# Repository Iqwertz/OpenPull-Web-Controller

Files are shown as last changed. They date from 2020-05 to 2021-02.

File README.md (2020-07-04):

# OpenPull-Web-Controller
---

## Introduction
The OpenPull-Web-Controller is an upgrade for the [DIY Universal test machine](https://github.com/CNCKitchen/Open-Pull) by [CNCKitchen](https://github.com/CNCKitchen).
It ads Bluetooth and Sd functionality to the test Maschine. 
The machine can be controlled over this webinterface: [https://iqwertz.github.io/OpenPullController/](https://iqwertz.github.io/OpenPullController/)

# Upgrade it
---

## Additional Hardware/ and Cad files
---

### CAD
There is an additional cad files for the Sdcard and Ble module holder available.

### Additional Hardware
- DC to Dc Buck Converter 24V-5V
- HM10 Ble Module
- Arduino MicroSD Card Module
- MicroSD Card

### Electronics
Currently the electronics are only as schematics and as images.
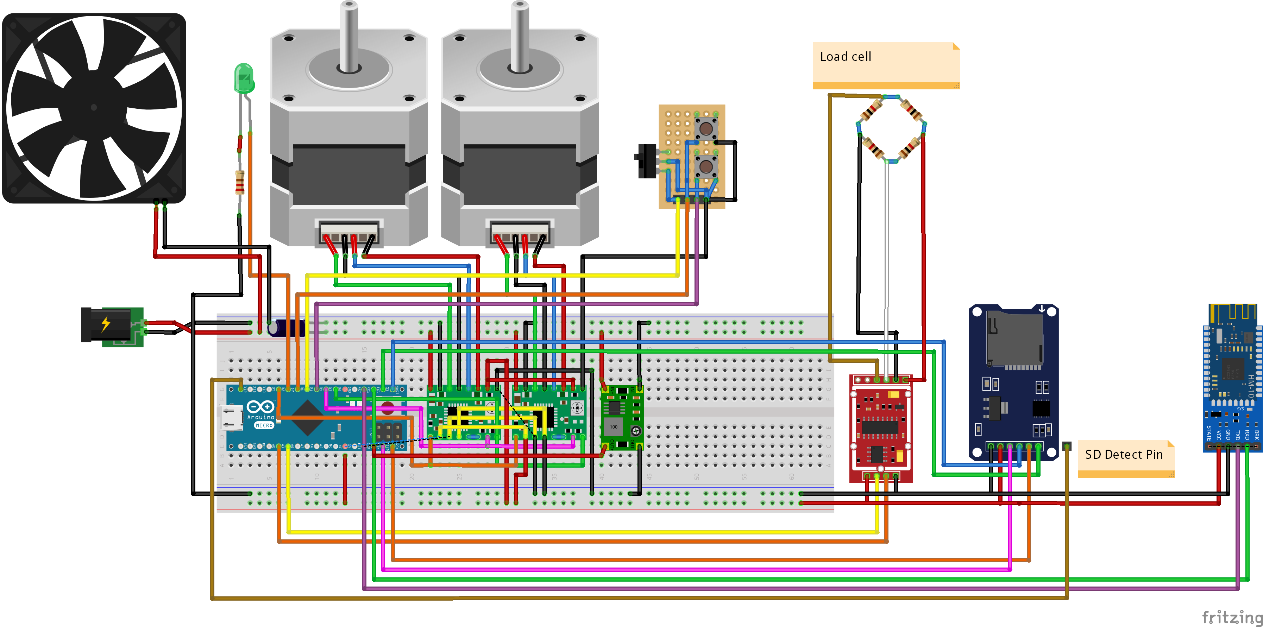
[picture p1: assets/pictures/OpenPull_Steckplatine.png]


Note:

My scematics are for an arduino micro since it was the only one laying around and it has integrated SPI and Serial pins. The code can be modified to use the arduino nano with the software serial library. If there is an interest for it add it as an issue.

Adding an Sd Detect Pin:

My SD card Module didn't had an Sd Detect pin but I found out that it can be added very easy. Just solder a wire to the left pin on the module (red circle in the Picture) and wire it according to the scematics.

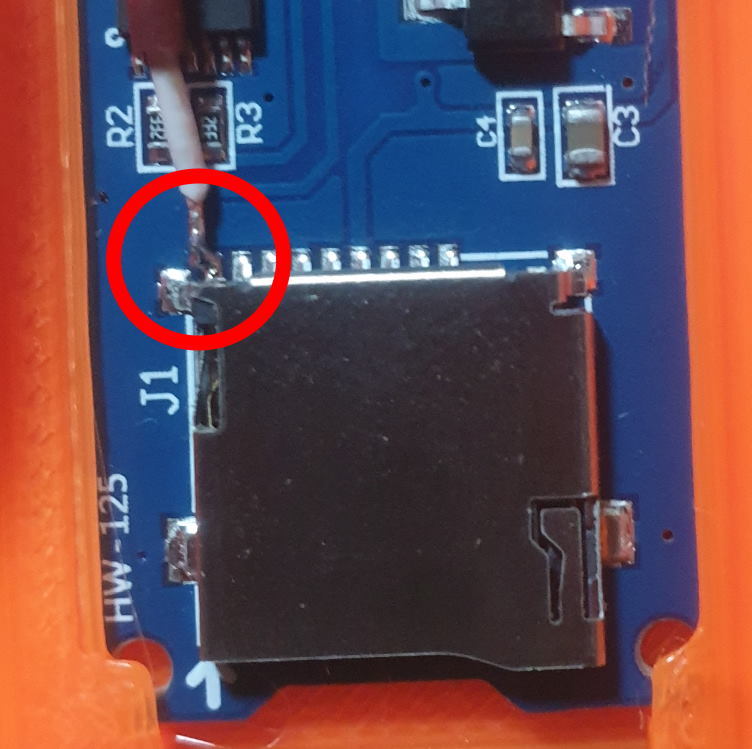
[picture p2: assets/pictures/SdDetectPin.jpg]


## Set Up
---

When everything is wired up, upload the OpenPull.ino to the arduino. Then insert an empty SDcard and plugin the power supply. The Maschine is now ready.

When the Maschine isnt moving the correct amount of distance you need to adjust the stepsPerMM var in the code.
```C++

long stepsPerMM = 39000;

```

## Use 
---

To use the Maschine go to [https://iqwertz.github.io/OpenPullController/](https://iqwertz.github.io/OpenPullController/).

Click on the Bluetooth Symbol in the Top left corner and select the Maschine (The Name is most of the time the producers Name. Mine is DSD Tech as an example.) When the connection is succesfull, you should be able to move it up and down by clicking the arrows.

### Interface
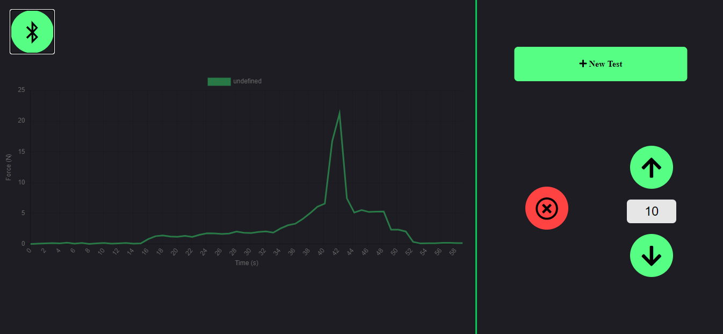
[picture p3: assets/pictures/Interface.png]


Notes:

With the red Button any Movement can be stopped

The number Field between the up/down arrows is the Move distance in mm when an arrow is clicked.
### Starting a new Test

To Start a new Test press the "New Test" Button

In the "New Test" Window, the Metadata of the Test can be set. It will be saved in the Test file. When the "Start Test" Button on the bottom of the page is pressed the Metadata will be sent the maschine and the test will be started.

Note:
When the progress indicator isnt increasing for some time reset the arduino and the page and retry.

### Data Processing
When an SD Card is inserted, test Data will get saved to it. It is located in an "OPENPULL" folder. 

!!!Important: Do not delete the index.txt file. It keeps track of the last file index. If you want to delete the whole Test Data delete the Folder!!!

To view the Test Data the [online Viewer](https://iqwertz.github.io/Visualizer/) can be used! 

Repository of the Data Visualizer: [github.com/Iqwertz/OpenPullTestDataVisualizer](https://github.com/Iqwertz/OpenPullTestDataVisualizer)

Example of a test File (JSON):

```JSON
{
  "MetaData": {
    "Name": "Infill 40%",
    "Date": "2020/05/28 19:32:53",
    "Parameter": {
      "Orientation": "Lying ",
      "Material": "PLA ",
      "Infill Type": "Gyroid ",
      "Orientation": "Lying ",
      "Material": "PLA ",
      "Infill Type": "Gyroid ",
      "Orientation": "Lying ",
      "Material": "PLA ",
      "Infill Type": "Gyroid ",
      "Infill": "15 %",
      "Layer Height": "0.3 mm",
      "First Layer Height": "0.3 mm",
      "Nozzle Size": "0.5 mm",
      "Bed Temperatur": "70 °",
      "Nozzle Temperatur": "200 °",
      "Vertical Shells": "3 ",
      "Top Layers": "3 ",
      "Bottom Layers": "3 "
    },
    "TestMode": "M14 A1",
    "Notes": ""
  },
  "Data": [
    0,
    1,
    3,
    6,
    10,
    0
  ],
  "MeasuringIntervall": 0.15,
  "BreakPoint": 419.00,
  "Maximum": 454.65
}
```

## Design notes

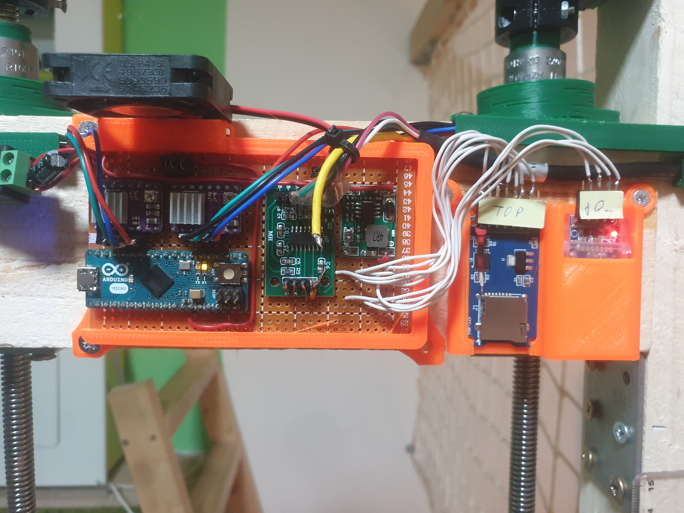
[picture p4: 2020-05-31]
assets/pictures/ElectronicsPhoto.jpg

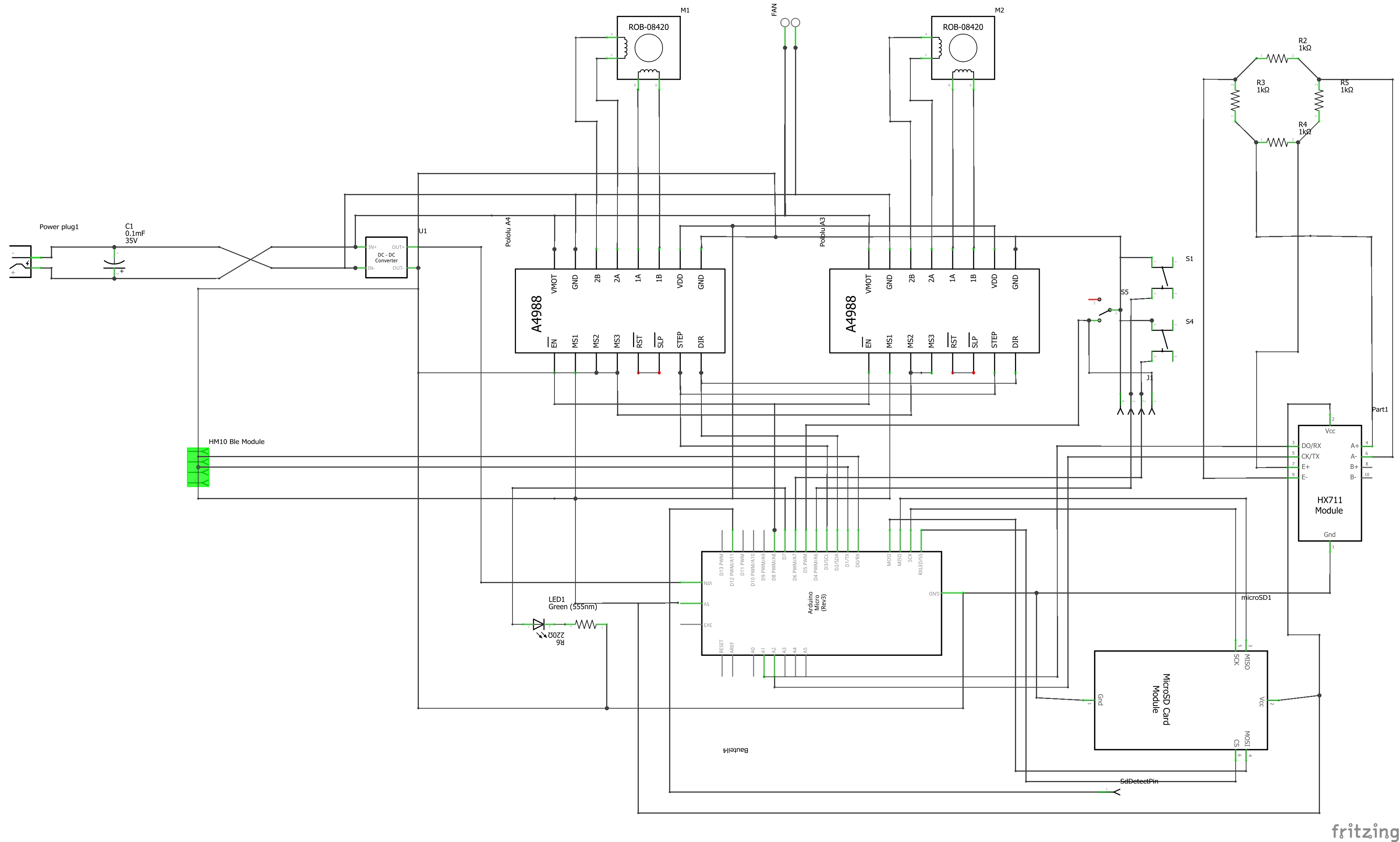
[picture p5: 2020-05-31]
OpenPull/Electronics/OpenPull_Schaltplan.png

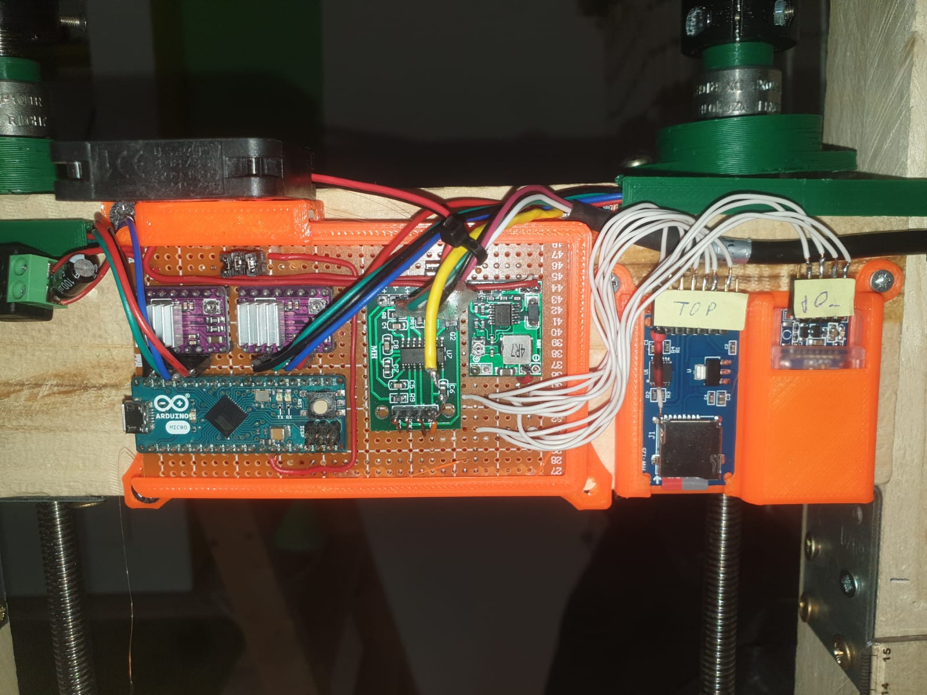
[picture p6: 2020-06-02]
OpenPull/CAD/UseofCases.jpeg

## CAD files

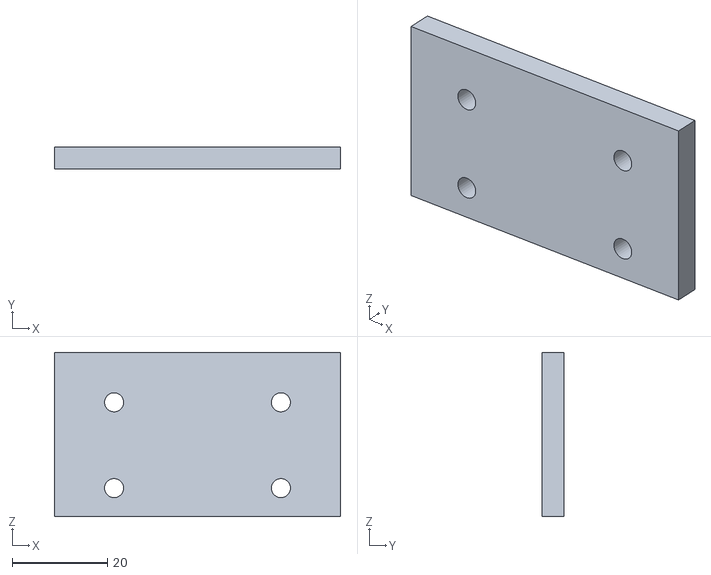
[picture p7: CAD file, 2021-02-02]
OpenPull/CAD/DriverTopSpacer.stl
60.0 x 4.70 x 34.5

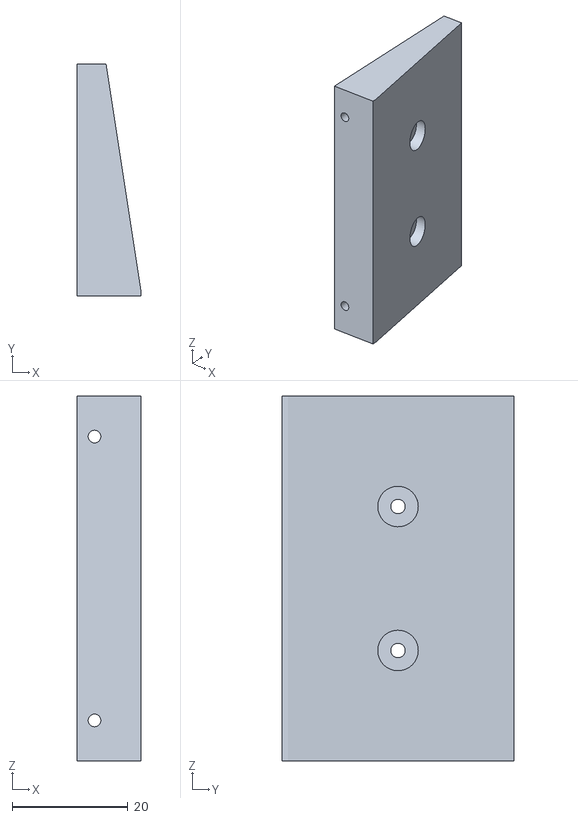
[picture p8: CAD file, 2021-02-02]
OpenPull/CAD/Schräge1.stl
11.0 x 40.0 x 63.0

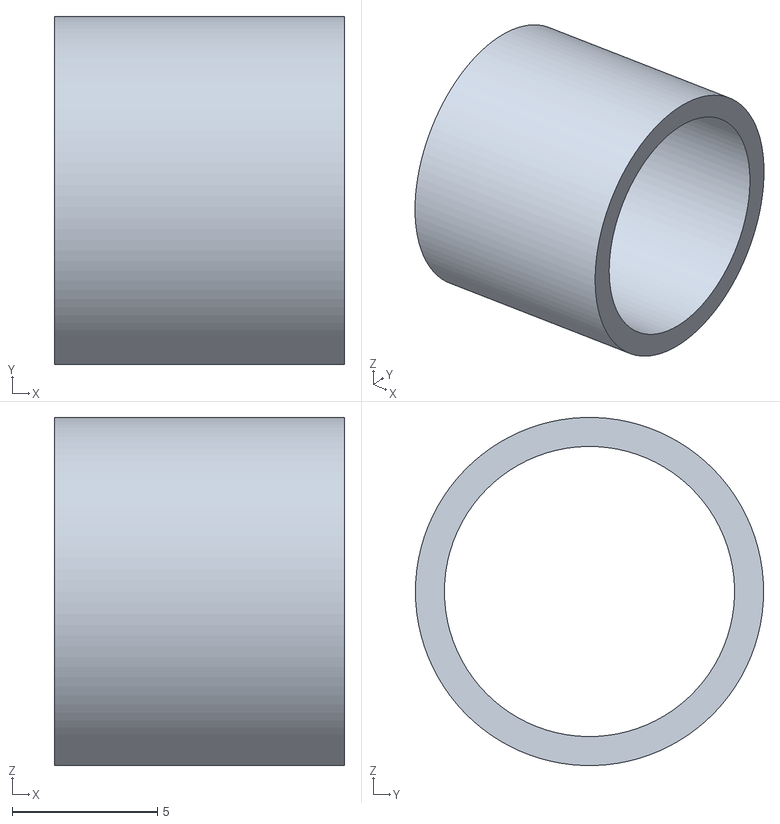
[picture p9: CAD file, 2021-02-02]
OpenPull/CAD/SPacer RS6201.stl
10.0 x 12.0 x 12.0

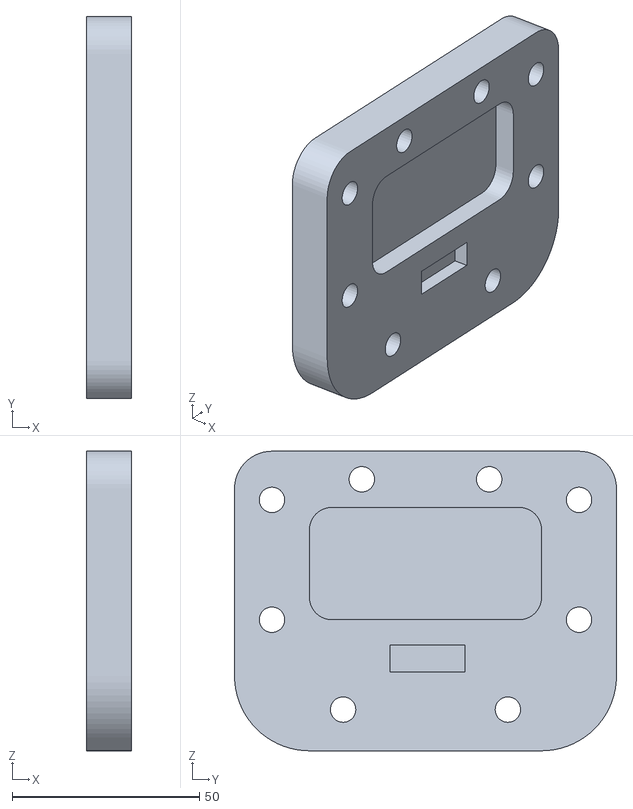
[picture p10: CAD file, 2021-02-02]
OpenPull/CAD/Clampback.stl
12.0 x 102.0 x 80.0

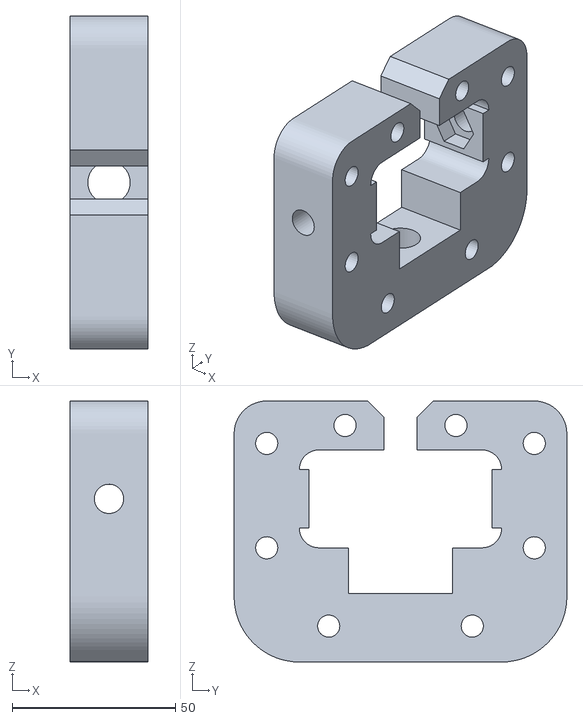
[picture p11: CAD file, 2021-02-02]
OpenPull/CAD/Clampcenterbot.stl
24.0 x 102.0 x 80.0

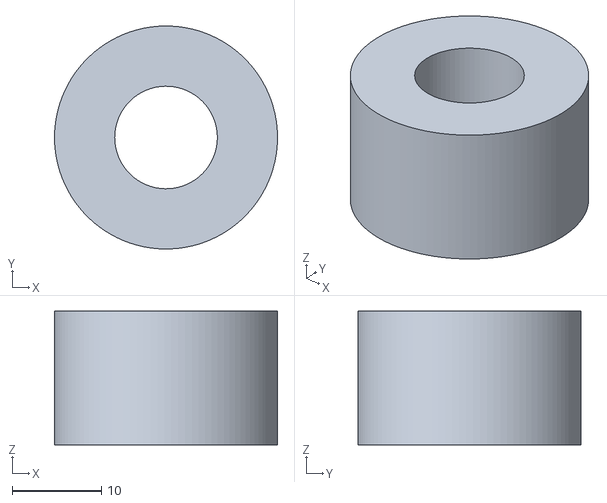
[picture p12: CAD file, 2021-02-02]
OpenPull/CAD/ClampSpaceHolder.stl
25.0 x 25.0 x 15.0

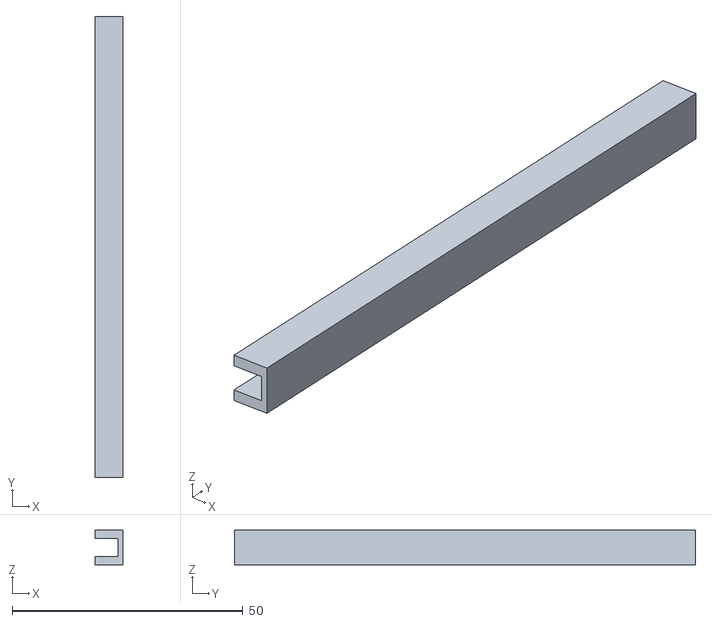
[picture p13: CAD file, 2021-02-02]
OpenPull/CAD/Leitung3.stl
6.00 x 100.0 x 7.50

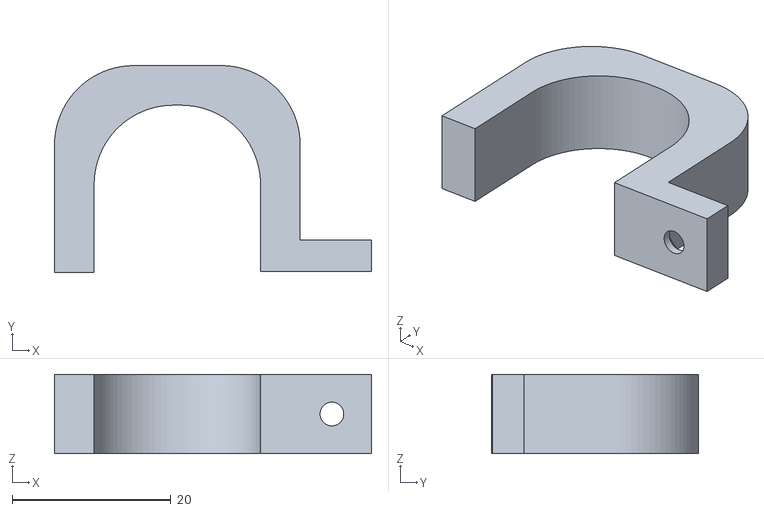
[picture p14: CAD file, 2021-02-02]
OpenPull/CAD/PSU Kabel Klemme.stl
40.0 x 26.1 x 10.0

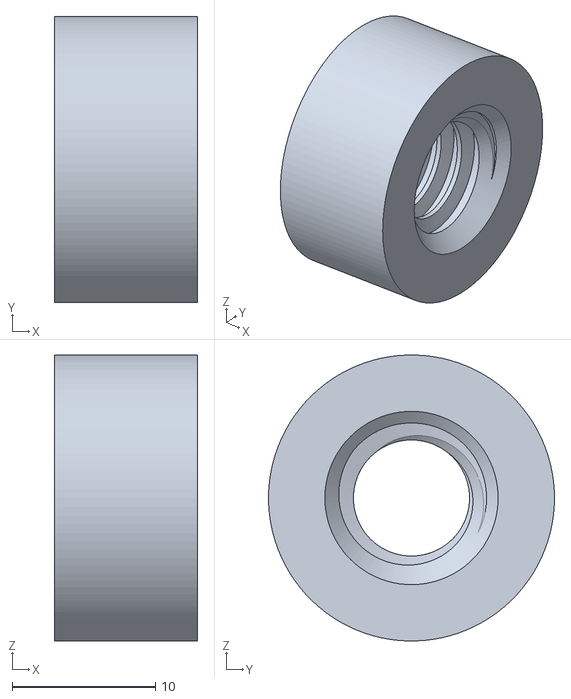
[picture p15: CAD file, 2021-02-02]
OpenPull/CAD/Counternut.stl
10.0 x 20.0 x 20.0

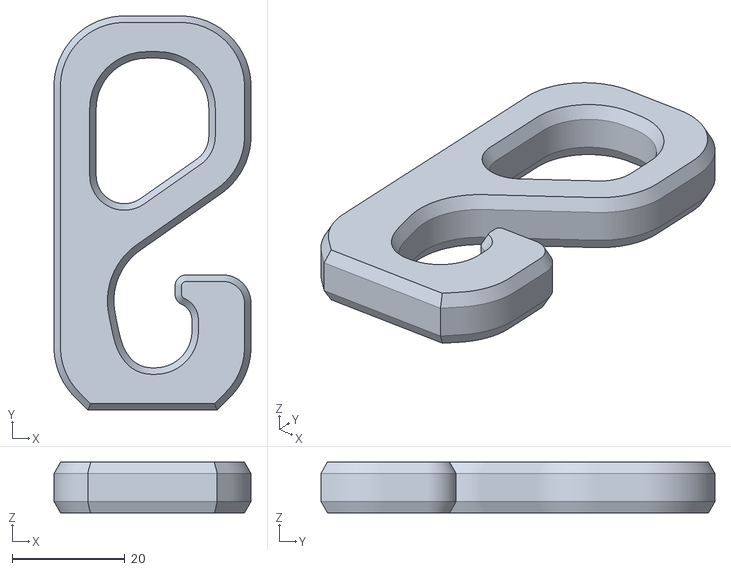
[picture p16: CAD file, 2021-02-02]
OpenPull/CAD/testHook_noSlots (1).stl
35.0 x 70.0 x 9.00

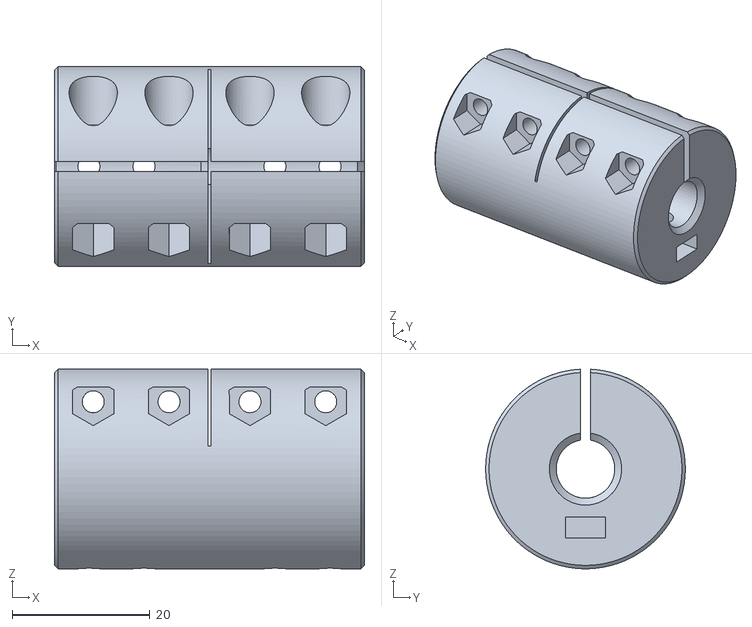
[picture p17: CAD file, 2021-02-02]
OpenPull/CAD/Coupling.stl
45.0 x 29.0 x 29.0

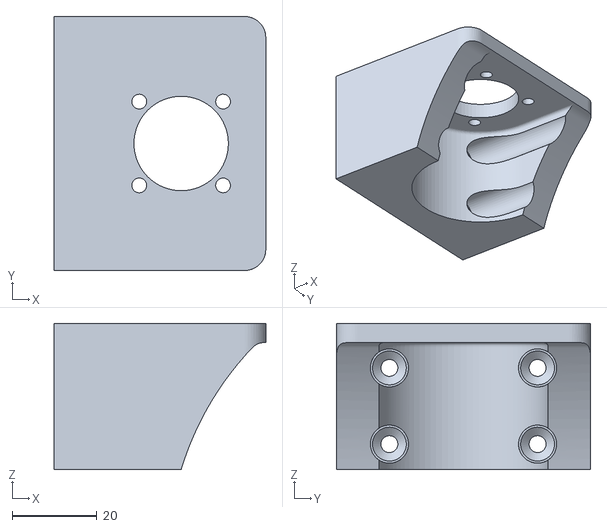
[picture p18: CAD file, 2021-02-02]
OpenPull/CAD/Driver.stl
50.0 x 60.0 x 34.5

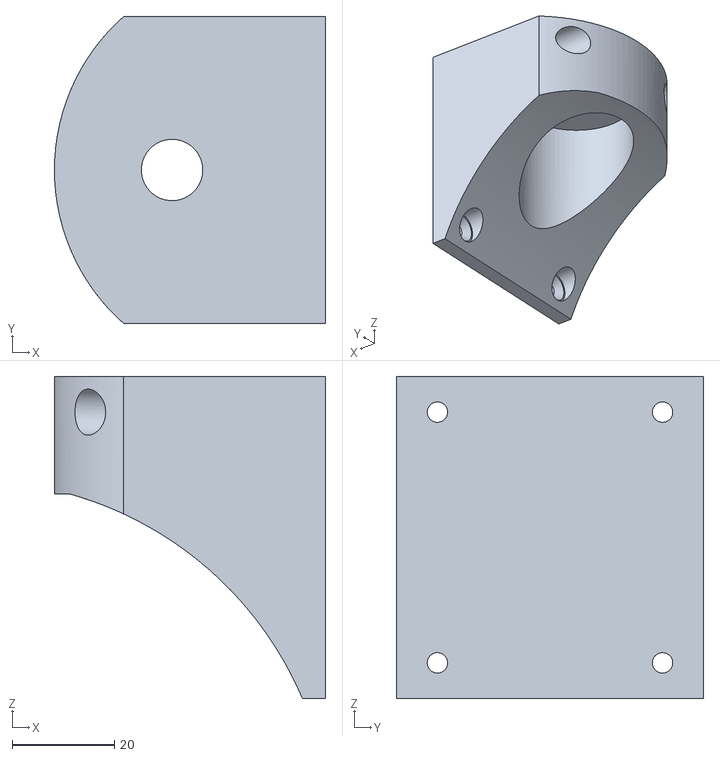
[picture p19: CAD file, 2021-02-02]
OpenPull/CAD/DriverBottom.stl
53.0 x 60.0 x 63.0

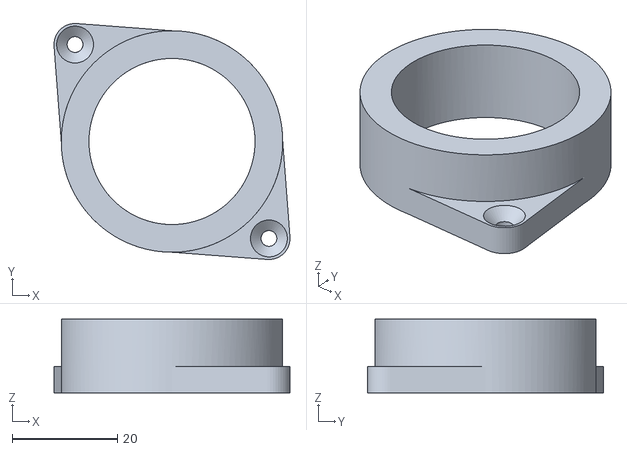
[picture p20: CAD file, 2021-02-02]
OpenPull/CAD/axialnutholder.stl
44.8 x 44.8 x 14.0

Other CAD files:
OpenPull/CAD/Spacer.stl
OpenPull/CAD/PSU CASE.stl
OpenPull/CAD/UHakenSpacer.stl
OpenPull/CAD/BleSdCase.stl
OpenPull/CAD/BleSdCardMount.stl
OpenPull/CAD/BoardMount.stl
OpenPull/CAD/Clampbreak.stl
OpenPull/CAD/Clampfront.stl
OpenPull/CAD/Dreher.stl
OpenPull/CAD/DriverBottomSpacer.stl
OpenPull/CAD/Electroniccase.stl
OpenPull/CAD/Leitung1.stl
OpenPull/CAD/Leitung2.stl
OpenPull/CAD/Loadcell Kabel Eck.stl
OpenPull/CAD/Loadcell Kabel Klemme.stl
OpenPull/CAD/Nut.stl
OpenPull/CAD/NutHolder.stl
OpenPull/CAD/PSU CASE Half.stl
OpenPull/CAD/PSU Eck.stl
OpenPull/CAD/Schräge2.stl
OpenPull/CAD/UHaken.stl

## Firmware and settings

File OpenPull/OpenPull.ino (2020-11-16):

/*########################################
  ##### OPEN PULL
  ##### DIY Universal Test Machnine, with ble and sd-card
  ##### V2.0
  ##### Stefan Hermann aka CNC Kitche
  ##### https://www.youtube.com/cnckitchen
  ##### 31.01.2019
  ##### Libraries:
  ##### HX711 by aguegu: https://github.com/aguegu/ardulibs/tree/master/hx711
  ##### Sd
  ##### SPI
  ########################################*/
//Current COde SIze: 28234 Programm
/* Libraries */
#include "hx711.h"
//#include <AccelStepper.h>
#include <SPI.h>
#include <SD.h>
#include <EEPROM.h>

////// Load Cell Variables

float gainValue = -875.7 * (1 - 0.001); //CALIBRATION FACTOR
float measuringIntervall = .5;       //Measuring interval when IDLE
float measuringIntervallTest = .5;  //Measuring interval during SLOW test
float measuringIntervallTestFast = .15; ///Measuring interval during FAST test
bool InvertMeasurments = true;  //inverts the Measurments to positve Values
const int MinStrength = 50;  //Minimum Strength of the Tests (Used for Auto Abort)
const int BreakMin = 10; //When the Value is smaller than this the test gets aborted (Used for Auto Abort)
long tareValue;
float SdWriteIntervall = .5;
bool WriteWhenTighten = true;  //When enabled the Data will be written to the Sd only when the sample is tightend (Force gets applied)
int TestStopDifferenz = 200;
int MaxNeg = -200; //Values below that durring tests get filterd out
////// Stepper Variables
byte pulseLength = 10;
long stepsPerMM = 39000;// 200 * 2 * (13 + 212.0 / 289.0) / 2; // Steps per rev * Microstepping * Gear reduction ratio / Pitch
float stepsPerSecond = stepsPerMM / 60; //1mm/min
int slowSpeedDelay = 3000;    //Time delay between steps for jogging slowly
int fastSpeedDelay = 300;     ////Time delay between steps for jogging fast
boolean dir = 0;
/////Stepper Linear Accel Settings
int StartSpeed = 1000; //Delay (ms) per Step at the Start of a Move
int EndSpeed = 80;  //Delay (ms) per Step when at full Speed
float AccelSteps = .5; //Slope of the Linear Acceleration

//////Dynamic Microstepping Settings
bool dynamicMicrostepping = true;
byte microSteppingPins[3] = {9, 10, 11};
bool microSteppingDefault[3] = {true, true, true};
bool microSteppingMove[3] = {false, false, false};

//Auto Home
byte endStopPin = 13;
int maxHomingDist = 230; //in mm
float HookOffset = 10;

long MoveStepsMM = 1400;
////// PIN definitions
int directionPin = 2;
int stepPin = 3;
int enablePin = 8;
int speedPin = 5;
int upPin = 4;
int downPin = 10;
int led1Pin = 7;
int sdDetectPin = 12;
///// Variables
byte mode = 2;
byte modeAddition = 0;
float currentSpeed = stepsPerSecond;    //SLOW Test speed
float fastSpeed = 25 * stepsPerSecond;  //FAST Test speed (x25 = 25mm/min)
long currentMicros = micros();
long lastLoadValues = 0;
long lastStep = 0;
String inputString;
float maxForce = 0;
float loweringCounter = 0;
long startTime = 0;
long yMTestTime = 30 * 1000; //Modulus Test time for SLOW speed (=30s)
bool debug = false; //debug mode to test the remote
bool WriteToSD = false;
bool SdInserted = false;
float MeasurmentMaxValue = 0;
float BreakPoint = 0;
const int LastMaxValuesSize = 5;    //Amount of the Last Values
float LastMaxValues[LastMaxValuesSize]; //Circular Buffer of the Last Max Values
byte LastMaxValuesIndex = 0;
bool AutoAbort = true;
/////Library Config
Hx711 loadCell(A1, A2);
String RootFolderName = "OpenPull";
int LastFileIndex;
File Data;
void setup() {
  // Serial (Serial1 is ble)
  Serial.begin(115200);
  Serial1.begin(19200);
  // Sd ini
  pinMode(sdDetectPin, INPUT_PULLUP);
  if (digitalRead(sdDetectPin) == 0) {
    //Serial.print("Initializing SD card...");
    if (!SD.begin()) {
      //Serial.println("initialization failed!");
    } else {
      SdInserted = true;
    }
    //Serial.println("initialization done.");
    delay(500);
    SdIni();
  }
  // Load Cell
  tareValue = loadCell.averageValue(32);
  // Stepper
  pinMode(directionPin, OUTPUT);
  pinMode(stepPin, OUTPUT);
  pinMode(enablePin, OUTPUT);
  digitalWrite(directionPin, dir);
  digitalWrite(stepPin, LOW);
  digitalWrite(enablePin, HIGH);
  // MicroStepping
  pinMode(microSteppingPins[0], OUTPUT);
  pinMode(microSteppingPins[1], OUTPUT);
  pinMode(microSteppingPins[2], OUTPUT);
  digitalWrite(microSteppingPins[0], microSteppingDefault[0]);
  digitalWrite(microSteppingPins[1], microSteppingDefault[1]);
  digitalWrite(microSteppingPins[2], microSteppingDefault[2]);

  pinMode(endStopPin, INPUT);
  //Up Button
  pinMode(upPin, INPUT);
  digitalWrite(upPin, HIGH);
  //Down Button
  pinMode(downPin, INPUT);
  digitalWrite(downPin, HIGH);
  //Speed Switch
  pinMode(speedPin, INPUT);
  digitalWrite(speedPin, HIGH);
  //LED Pin
  pinMode(led1Pin, OUTPUT);
  digitalWrite(led1Pin, LOW);

  //read saved Offset
  HookOffset = EEPROM.read(0);

}
void loop() {
  /////////Sd
  CheckSd();
  /////////////Ble Settings
  int stringRead = 0;
  //Serial COmmunication
  inputString = "";
  while (Serial1.available())
  {
    inputString = Serial1.readString();
    if (inputString == "NEW") {
      BleNewTest();
    } else if (inputString == "SdStat") {
      if (!SdInserted) {
        Serial1.println("SDfalse");
      }
    }
    stringRead = 1;
  }
  while (Serial.available())
  {
    inputString = Serial.readString();
    stringRead = 1;
  }
  if (stringRead == 1) {
    String taskPart;
    String rest;
    taskPart = inputString.substring(0, inputString.indexOf(" "));
    rest = inputString.substring(inputString.indexOf(" ") + 1);
    if (taskPart == "S") {
      AbortTest();
    } else if (taskPart == "G0") {
      Move(rest.toInt());
    } else if (taskPart == "G28") {
      Home(rest.toInt());
    } else if (taskPart == "M206") {
      SetOffset();
    } else if (taskPart == "M10") { //Start SLOW test
      digitalWrite(enablePin, LOW);
      mode = 1;
      if (rest == "S1") {
        modeAddition = 1;
      } else if (rest == "A0") {
        AutoAbort = false;
      } else if (rest == "A1") {
        AutoAbort = true;
      }
      measuringIntervall = measuringIntervallTest;
      maxForce = 0;
      loweringCounter = 0;
      digitalWrite(directionPin, LOW);
      printSpaces(5);
      Log("Tare");
      tareValue = loadCell.averageValue(32);    //Tare
      Log("Start Test");
      digitalWrite(led1Pin, HIGH);
      delay(500);
      digitalWrite(led1Pin, LOW);
      delay(200);
      digitalWrite(led1Pin, HIGH);
      delay(500);
      digitalWrite(led1Pin, LOW);
    } else if (taskPart == "M11") { //manual Mode (not implemented yet)
      Log("Manual Mode");
      digitalWrite(enablePin, LOW);
      measuringIntervall = 2;
      mode = 2;
    } else if (taskPart == "M12") { //tare
      digitalWrite(enablePin, LOW);
      measuringIntervall = 2;
      Log("Tare");
      tareValue = loadCell.averageValue(32);
    } else if (taskPart == "M13") { //Youngs Modulus Test Mode
      if (rest == "A0") {
        AutoAbort = false;
      } else if (rest == "A1") {
        AutoAbort = true;
      }
      digitalWrite(enablePin, LOW);
      mode = 4;
      measuringIntervall = measuringIntervallTest;
      maxForce = 0;
      loweringCounter = 0;
      digitalWrite(directionPin, LOW);
      printSpaces(5);
      Log("Tare");
      tareValue = loadCell.averageValue(32);
      Log("Start Test");
      digitalWrite(led1Pin, HIGH);
      delay(500);
      digitalWrite(led1Pin, LOW);
      delay(200);
      digitalWrite(led1Pin, HIGH);
      delay(500);
      digitalWrite(led1Pin, LOW);
      startTime = millis();
    } else if (taskPart == "M14") { //Start FAST test
      if (rest == "A0") {
        AutoAbort = false;
      } else if (rest == "A1") {
        AutoAbort = true;
      }
      digitalWrite(enablePin, LOW);
      mode = 3;
      measuringIntervall = measuringIntervallTestFast;
      maxForce = 0;
      loweringCounter = 0;
      digitalWrite(directionPin, LOW);
      printSpaces(5);
      Log("Tare");
      tareValue = loadCell.averageValue(32);
      Log("Start Fast Test");
      digitalWrite(led1Pin, HIGH);
      delay(500);
      digitalWrite(led1Pin, LOW);
      delay(200);
      digitalWrite(led1Pin, HIGH);
      delay(500);
      digitalWrite(led1Pin, LOW);
    } else {
      Log("ERROR: Command not found!");
    }
  }
  ///////////////// Tensile Test Mode ////////////
  if (mode == 1) {
    TensileTest();
    ///////////////// MANUAL MODE //////////////////
  } else if (mode == 2) {
    ManualMode();
    // Fast Test Mode
  } else if (mode == 3) {
    FastTest();
    // Youngs Modulus Test
  } else if (mode == 4) {
    YoungsModule();
  }
  ///////////// Get load value
  currentMicros = micros();
  if ((micros() - lastLoadValues) >= measuringIntervall * 1000000) {
    digitalWrite(led1Pin, HIGH);
    float loadValue = CalcLoadValue();
    //Serial.println(loadValue);
    Serial1.println(String("V") + loadValue);
    if (WriteToSD) {
      if (WriteWhenTighten) {
        if (loadValue > 5) {
          File TestFile = SD.open(RootFolderName + "/" + LastFileIndex + ".txt", FILE_WRITE);
          TestFile.println(loadValue + String(","));
          TestFile.close();
        }
      } else {
        File TestFile = SD.open(RootFolderName + "/" + LastFileIndex + ".txt", FILE_WRITE);
        TestFile.println(loadValue + String(","));
        TestFile.close();
      }
    }
    digitalWrite(led1Pin, LOW);
    lastLoadValues = currentMicros;
    if (mode == 1 && modeAddition == 1) {
      if (loadValue >= maxForce) {
        maxForce = loadValue;
        loweringCounter = 0;
      } else {
        loweringCounter++;
      }
      if (loweringCounter >= 20) {
        currentSpeed = currentSpeed * 4;
        modeAddition = 0;
      }
    }
    if (mode != 2) {
      if (loadValue > MeasurmentMaxValue) {
        MeasurmentMaxValue = loadValue;
      }
      PushToBuffer(loadValue);
      if (MeasurmentMaxValue > MinStrength) {
        if (loadValue < BreakMin) {
          BreakPoint = 0;
          for (int i = 0; i < LastMaxValuesSize; i++) {
            if (BreakPoint <= LastMaxValues[i]) {
              BreakPoint = LastMaxValues[i];
            }
          }
          if (loadValue > MaxNeg) {
            if (AutoAbort) {
              AbortTest();
            }
          }
        }
      }
    }
  }
}

void SetMicroStepping(bool steppingPins[3]) {
  if (dynamicMicrostepping) {
    digitalWrite(microSteppingPins[0], steppingPins[0]);
    digitalWrite(microSteppingPins[1], steppingPins[1]);
    digitalWrite(microSteppingPins[2], steppingPins[2]);
  }
}

float CalcLoadValue() {
  float lV = (loadCell.averageValue(1) - tareValue) / gainValue;
  if (InvertMeasurments) {
    lV = lV * -1;
  }
  return lV;
}
long Move(int distance) {  //This function moves the Maschine the given amount of mm
  long movedSteps = 0;
  SetMicroStepping(microSteppingMove);
  digitalWrite(enablePin, LOW);
  if (distance < 0) {
    digitalWrite(directionPin, HIGH);
  } else {
    digitalWrite(directionPin, LOW);
  }
  long Steps = MoveStepsMM * abs(distance);
  long LastMillis = millis();
  float StepDelay = StartSpeed;
  int DecellerationSteps = (StartSpeed - EndSpeed) / AccelSteps;
  for (long i = 0; i <= Steps; i++) {  //Acceleration was implemented because the motors wouldnt spin when started to fast.
    if (Steps - i < DecellerationSteps) {
      if (StepDelay < StartSpeed) {
        StepDelay += AccelSteps;
      }
    } else {
      if (StepDelay >= EndSpeed) {
        StepDelay -= AccelSteps;
      } else {
        StepDelay = EndSpeed;
      }
    }
    digitalWrite(stepPin, HIGH);

    /////This can be used to stop move when there is a load on it but then the motors will click every .5 s, due to the time it takes to read the LoadCell
    if (millis() - LastMillis >= 500) {
      long cStart=millis();

      float CValue = CalcLoadValue();
      if (CValue >= 20) {
        i = Steps;
        movedSteps=-1;
      }
      LastMillis = millis();

      delayMicroseconds(floor(StepDelay)-(millis()-cStart)); 
      delayMicroseconds(floor(StepDelay));
    } else {
      delayMicroseconds(floor(StepDelay));
    }

    digitalWrite(stepPin, LOW);
    movedSteps = i;
    if (Serial1.available()) {
      if (Serial1.readString() == "S ") {
        i = Steps;
      }
    }
    if (!digitalRead(endStopPin) && distance < 0) {
      i = Steps;
    }
  }
  delay(100);
  digitalWrite(enablePin, HIGH);
  SetMicroStepping(microSteppingDefault);

  return movedSteps;
}

void Home(int Offset) {
  if (digitalRead(endStopPin)) {
    Move(1);
    Move(maxHomingDist * -1);
    if (Offset >= 0) {
      Move(Offset);
    } else {
      Move(HookOffset);
    }
  } else {
    Serial1.println("ANo Endstop Connected");
  }
}

void SetOffset() {
  if (digitalRead(endStopPin)) {
    HookOffset = (float)Move(maxHomingDist * -1) / (float)MoveStepsMM;
    if (HookOffset >= 0) {
      EEPROM.write(0, HookOffset);
    }
    Move(HookOffset);
  } else {
    Serial1.println("ANo Endstop Connected");
  }
}
void printSpaces(int numberOfSpaces) { //This function will print a given amount of empty lines
  for (int i = numberOfSpaces; i > 0; i--) {
    Log("");
  }
}
void Log(String msg) {
  Serial.println(msg);
  //  Serial1.println("C" + msg);
}
void TensileTest() {
  currentMicros = micros();
  if ((currentMicros - lastStep) >= 1000000. / currentSpeed) {
    digitalWrite(stepPin, HIGH);
    delayMicroseconds(pulseLength);
    digitalWrite(stepPin, LOW);
    lastStep = currentMicros;
  }
  if (!digitalRead(downPin)) { //Stop test if DOWN Button is pressed
    AbortTest();
  }
}
void ManualMode() {
  boolean performStep = 0;
  if (!digitalRead(upPin)) {
    digitalWrite(directionPin, LOW);
    performStep = 1;
    if (debug) {
      Log("UP");
    }
  } else if (!digitalRead(downPin)) {
    digitalWrite(directionPin, HIGH);
    performStep = 1;
    if (debug) {
      Log("DOWN");
    }
  }
  //Perform Step
  if (performStep) {
    digitalWrite(stepPin, HIGH);
    delayMicroseconds(pulseLength);
    digitalWrite(stepPin, LOW);
  }
  if (digitalRead(speedPin)) {
    delayMicroseconds(slowSpeedDelay);
    if (debug) {
      Log("Slow Speed");
    }
  } else {
    delayMicroseconds(fastSpeedDelay);
    if (debug) {
      Log("Fast Speed");
    }
  }
}
void FastTest() {
  currentMicros = micros();
  if ((currentMicros - lastStep) >= 1000000. / fastSpeed) {
    digitalWrite(stepPin, HIGH);
    delayMicroseconds(pulseLength);
    digitalWrite(stepPin, LOW);
    lastStep = currentMicros;
  }
  if (!digitalRead(downPin)) {
    AbortTest();
  }
}
void YoungsModule() {
  currentMicros = micros();
  if ((currentMicros - lastStep) >= 1000000. / currentSpeed) {
    digitalWrite(stepPin, HIGH);
    delayMicroseconds(pulseLength);
    digitalWrite(stepPin, LOW);
    lastStep = currentMicros;
  }
  if (millis() - startTime >= yMTestTime) {
    mode = 3;
    measuringIntervall = measuringIntervallTestFast;
  }
  if (!digitalRead(downPin)) {
    AbortTest();
  }
}
void AbortTest() {
  Log("Test aborted - entering manual mode");
  if (SdInserted) {
    File TestFile = SD.open(RootFolderName + "/" + LastFileIndex + ".txt", FILE_WRITE);
    TestFile.println(0);
    TestFile.println("],");
    TestFile.println(String("\"MeasuringIntervall\":") + measuringIntervall + String(","));
    TestFile.println(String("\"BreakPoint\":") + BreakPoint + String(","));
    TestFile.println(String("\"Maximum\":") + MeasurmentMaxValue);
    TestFile.println("}");
    TestFile.close();
  }
  Serial1.println(String("FinTest B") + BreakPoint + String(";M") + MeasurmentMaxValue );
  printSpaces(5);
  WriteToSD = false;
  mode = 2;
  modeAddition = 0;
  measuringIntervall = .5;
  currentSpeed = stepsPerSecond;
  MeasurmentMaxValue = 0;
  digitalWrite(enablePin, HIGH);
}
void GetLastSdIndex() {
  File Index;
  if (SD.exists(RootFolderName + "/INDEX.txt")) {
    String i;
    Index = SD.open(RootFolderName + "/INDEX.txt");
    if (Index.available())
    {
      i = Index.readStringUntil(';');
    }
    LastFileIndex = i.toInt();
    Index.close();
  } else {
    Index = SD.open(RootFolderName + "/INDEX.txt", FILE_WRITE);
    Index.println("0;");
    Index.close();
    LastFileIndex = 0;
  }
}
//this function handles the new test send protocol
//The Send Protocoll is:
//The PC sends "NEW" to make a new File on the maschine and set it into testdata recieve mode
//The Maschine sends "OK NEW" to confirm that a new test is started
//The PC sends the string of the first index in the BleAddTestSendArray
//The Maschine receives the data and sends it back
//The Pc check if the sent data was correct. If it was it sends "OK" and the next line. In not it sends "FALSE" and it resends the same data with a delay of 300milliseconds to avoid "gatt opertion in progress" error
//If the Maschine receives "OK" it writes the last data to the current file and it sends the new received data back, if "FALSE" or anything else it delets the received data
//This sending loop repeats until every string in the BleAddTestSendArray is sent
//When everything in the BleAddTestSendArray is sent the Pc sents "OKEND " with the Test Mode
//WHen the Maschine receives "OKEND" it closes the opened file and starts the test with the received test mode
//I implemented this send protocol to make sure the sent data is 100% correct (When developing I often had faulty data which destroyed everything)
void BleNewTest() {
  File NewTest;
  if (SdInserted) {
    LastFileIndex++;
    File N;
    N = SD.open(RootFolderName + "/INDEX.txt", O_READ | O_WRITE | O_CREAT | O_TRUNC);
    N.println(LastFileIndex);
    N.close();
    NewTest = SD.open(RootFolderName + "/" + LastFileIndex + ".txt", FILE_WRITE);
    Serial1.println("OK NEW");
  } else {
    Serial1.println("OK NEW NOSD");
  }
  //Serial.println("New Test");
  bool FinishedIni = false;
  String LastString = "";
  String NextInput = "";
  while (!FinishedIni) {
    if (Serial1.available() || NextInput != "") {
      String s;
      if (Serial1.available()) {
        s = Serial1.readString();
      } else {
        s = NextInput;
        NextInput = "";
      }
      Serial.println(s);
      if (LastString == "") {
        if (s.substring(0, s.indexOf(" ")) == "END") {
          FinishedIni = true;
          if (SdInserted) {
            NewTest.println("\"Data\": [");
            NewTest.close();
            WriteToSD = true;
          }
          inputString = s.substring(s.indexOf(" ") + 1) + " ";
          Serial1.println("Finished");
        } else {
          LastString = s;
          Serial1.println(LastString);
          //Serial.println(LastString);
        }
      } else if (s.substring(0, 2) == "OK") {
        if (SdInserted) {
          NewTest.println(LastString);
        }
        //Serial.println(LastString);
        LastString = "";
        NextInput = s.substring(2);
      } else {
        //Serial.println("Deleted Line");
        LastString = "";
      }
    }
  }
}
void PushToBuffer(int V) {
  LastMaxValuesIndex++;
  if (LastMaxValuesIndex == LastMaxValuesSize) {
    LastMaxValuesIndex = 0;
  }
  LastMaxValues[LastMaxValuesIndex] = V;
}
void CheckSd() {
  if (SdInserted) {
    if (digitalRead(sdDetectPin) == 1) {
      SdInserted = false;
      Serial1.println("AAttention! Sd Card got removed. No data will be recorded");
    }
  } else {
    if (digitalRead(sdDetectPin) == 0) {
      delay(100);
      if (SD.begin()) {
        SdInserted = true;
        delay(500);
        SdIni();
        Serial1.println("ASd Card got Inserted");
      }
    }
  }
  //Serial.print(digitalRead(sdDetectPin));
  //Serial.print(",");
  //Serial.println(SdInserted);
}
//////Function that Initializes Sd Card and Creates Directory if missing
void SdIni() {
  if (SdInserted) {
    SD.mkdir("/" + RootFolderName);
    GetLastSdIndex();
  }
}

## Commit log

2020-05-24 Added Config File and Implemented Reset button
2020-05-24 Added Arduino Code
2020-05-26 Disabled Move Buttons during Test
2020-05-28 Only Write when Tighten Option Added
    [OpenPull.ino]
2020-05-28 FIxed No Sd Bug
    [OpenPull.ino]
2020-05-29 Updated Fritzing files
    [OpenPull.fzz]
2020-05-31 Updated Pictures
    [OpenPull.fzz]
2020-08-03 Added Linear Acceleration
    Should fix the bug, that the motors arent moving sometimes
    [OpenPull.ino]
2020-10-31 added Homing buttons
2021-02-02 added stls
    [BleSdCase.stl, ClampSpaceHolder.stl, Clampback.stl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]
